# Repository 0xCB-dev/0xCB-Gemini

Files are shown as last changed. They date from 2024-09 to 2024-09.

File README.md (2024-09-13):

# 0xCB-Gemini

### 0xCB Helios little brother - waveshare zero compatible

| Licence | OSHWA |
| :---: | :---: |
|  | (https://certification.oshwa.org/de000147.html) |

### Official vendors

Purchasing Gemini from any vendors listed here directly supports our work. Gemini controllers sourced from vendors not listed here and not produced by us will not receive the same level of support and may have varying degrees of quality.

### EU:

Germany: [KeebSupply](https://keeb.supply/products/0xcb-gemini)

Germany: [Keycapsss](https://keycapsss.com/keyboard-parts/mcu-controller/277/0xcb-gemini-waveshare-rp2040-zero-compatible-microcontroller)

### North America:

America: Ringer Keys (Coming soon!)

#### Flashing

- `qmk clone`
- `cd qmk_firmware`
- To go to bootloader press the reset button longer than 500ms and release. Alternatively you can short the RST pin to GND, as it's wired to the reset button.
- `make 0xcb/gemini:default:flash`

### Assembly

The PCBs are assembled at the fab with the production files located in the /kikit/prod/ dir.

### Integration in your own design

- Waveshare zero footprint
- more to come

### PCB

KiCad 8 stable

[Schematic](https://github.com/0xCB-dev/0xcb-Gemini/blob/main/rev1.0/gemini.pdf)

### Pinout

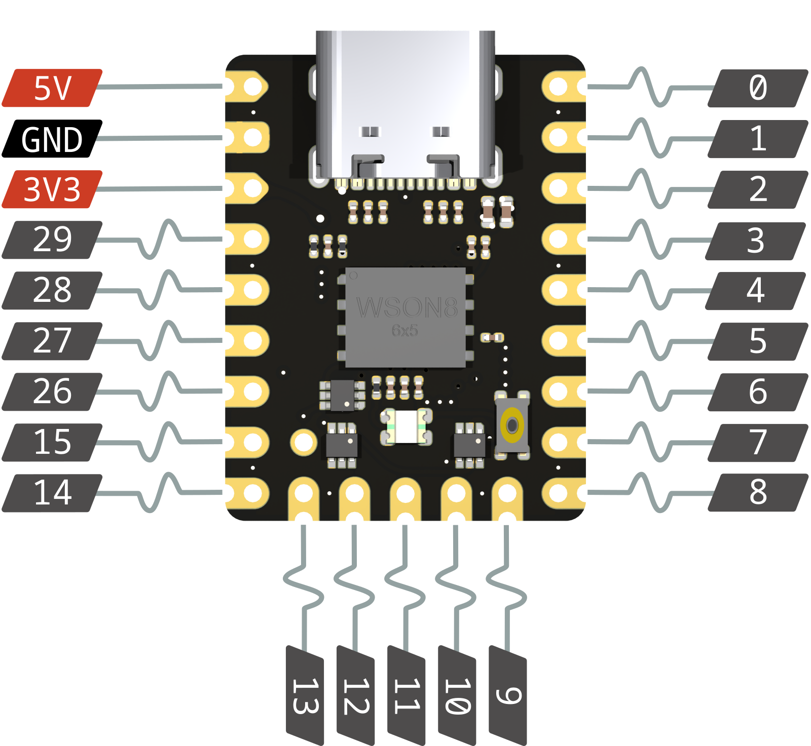
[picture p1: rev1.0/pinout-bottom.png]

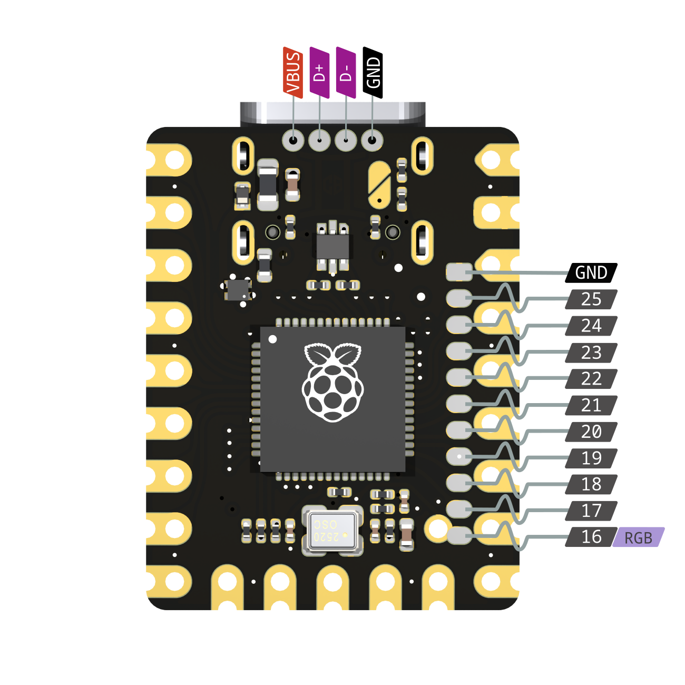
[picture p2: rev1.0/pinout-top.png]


| GPIO | F1 | F2 | F3 | F4 | F5  | F6 | F7 | F8 | F9 |
| ---- | --- | --- | --- | --- | --- | ---- | ---- | --- | --- |
| 0 | SPI0 RX  | UART0 TX  | I2C0 SDA | PWM0 A | SIO | PIO0 | PIO1 | | USB OVCUR DET |
| 1 | SPI0 CSn | UART0 RX  | I2C0 SCL | PWM0 B | SIO | PIO0 | PIO1 | | USB VBUS DET  |
| 2 | SPI0 SCK | UART0 CTS | I2C1 SDA | PWM1 A | SIO | PIO0 | PIO1 | | USB VBUS EN |
| 3 | SPI0 TX  | UART0 RTS | I2C1 SCL | PWM1 B | SIO | PIO0 | PIO1 | | USB OVCUR DET |
| 4 | SPI0 RX  | UART1 TX  | I2C0 SDA | PWM2 A | SIO | PIO0 | PIO1 | | USB VBUS DET  |
| 5 | SPI0 CSn | UART1 RX  | I2C0 SCL | PWM2 B | SIO | PIO0 | PIO1 | | USB VBUS EN |
| 6 | SPI0 SCK | UART1 CTS | I2C1 SDA | PWM3 A | SIO | PIO0 | PIO1 | | USB OVCUR DET |
| 7 | SPI0 TX  | UART1 RTS | I2C1 SCL | PWM3 B | SIO | PIO0 | PIO1 | | USB VBUS DET  |
| 8 | SPI1 RX  | UART1 TX  | I2C0 SDA | PWM4 A | SIO | PIO0 | PIO1 | | USB VBUS EN |
| 9 | SPI1 CSn | UART1 RX  | I2C0 SCL | PWM4 B | SIO | PIO0 | PIO1 | | USB OVCUR DET |
| 10 | SPI1 SCK | UART1 CTS | I2C1 SDA | PWM5 A | SIO | PIO0 | PIO1 | | USB VBUS DET  |
| 11 | SPI1 TX  | UART1 RTS | I2C1 SCL | PWM5 B | SIO | PIO0 | PIO1 | | USB VBUS EN |
| 12 | SPI1 RX  | UART0 TX  | I2C0 SDA | PWM6 A | SIO | PIO0 | PIO1 | | USB OVCUR DET |
| 13 | SPI1 CSn | UART0 RX  | I2C0 SCL | PWM6 B | SIO | PIO0 | PIO1 | | USB VBUS DET  |
| 14 | SPI1 SCK | UART0 CTS | I2C1 SDA | PWM7 A | SIO | PIO0 | PIO1 | | USB VBUS EN |
| 15 | SPI1 TX  | UART0 RTS | I2C1 SCL | PWM7 B | SIO | PIO0 | PIO1 | | USB OVCUR DET |
| 16 | SPI0 RX  | UART0 TX  | I2C0 SDA | PWM0 A | SIO | PIO0 | PIO1 | | USB VBUS DET  |
| 17 | SPI0 CSn | UART0 RX  | I2C0 SCL | PWM0 B | SIO | PIO0 | PIO1 | | USB VBUS EN |
| 18 | SPI0 SCK | UART0 CTS | I2C1 SDA | PWM1 A | SIO | PIO0 | PIO1 | | USB OVCUR DET |
| 19 | SPI0 TX  | UART0 RTS | I2C1 SCL | PWM1 B | SIO | PIO0 | PIO1 | | USB VBUS DET  |
| 20 | SPI0 RX  | UART1 TX  | I2C0 SDA | PWM2 A | SIO | PIO0 | PIO1 | CLOCK GPIN0  | USB VBUS EN |
| 21 | SPI0 CSn | UART1 RX  | I2C0 SCL | PWM2 B | SIO | PIO0 | PIO1 | CLOCK GPOUT0 | USB OVCUR DET |
| 22 | SPI0 SCK | UART1 CTS | I2C1 SDA | PWM3 A | SIO | PIO0 | PIO1 | CLOCK GPIN1  | USB VBUS DET  |
| 23 | SPI0 TX  | UART1 RTS | I2C1 SCL | PWM3 B | SIO | PIO0 | PIO1 | CLOCK GPOUT1 | USB VBUS EN |
| 24 | SPI1 RX  | UART1 TX  | I2C0 SDA | PWM4 A | SIO | PIO0 | PIO1 | CLOCK GPOUT2 | USB OVCUR DET |
| 25 | SPI1 CSn | UART1 RX  | I2C0 SCL | PWM4 B | SIO | PIO0 | PIO1 | CLOCK GPOUT3 | USB VBUS DET  |
| 26 | SPI1 SCK | UART1 CTS | I2C1 SDA | PWM5 A | SIO | PIO0 | PIO1 | | USB VBUS EN |
| 27 | SPI1 TX  | UART1 RTS | I2C1 SCL | PWM5 B | SIO | PIO0 | PIO1 | | USB OVCUR DET |
| 28 | SPI1 RX  | UART0 TX  | I2C0 SDA | PWM6 A | SIO | PIO0 | PIO1 | | USB VBUS DET  |
| 29 | SPI1 CSn | UART0 RX  | I2C0 SCL | PWM6 B | SIO | PIO0 | PIO1 | | USB VBUS EN |

### Credits

Uses the same reset circuit found on the [0xCB-Helios](https://github.com/0xCB-dev/0xcb-Helios) which in turn is based on the one used on the [Sea-picro](https://github.com/joshajohnson/sea-picro) by joshajohnson and this very well written [article](https://acheronproject.com/reset_article_1/reset_article_1/) by the Acheron Project.

Thank you! :heart:

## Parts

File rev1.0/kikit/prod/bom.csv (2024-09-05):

Comment | Designator | Footprint | LCSC
100n | C6,C11,C12,C13,C14,C15,C16,C17,C18,C19,C20 | gemini:C_0201_0603Metric | C576431
RP2040 | U4 | gemini:RP2040-QFN-56 | C2040
10k | R1,R2,R3,R10,R16 | gemini:R_0201_0603Metric | C138117
15p | C7,C8 | gemini:C_0201_0603Metric | C85891
10u | C1,C3,C4,C5 | gemini:C_0402_1005Metric | C15525
51k | R4,R5,R6 | gemini:R_0201_0603Metric | C295806
1u | C9,C10 | gemini:C_0201_0603Metric | C76935
4.7u | C2 | gemini:C_0201_0603Metric | C335103
2N7002VC- | Q1,Q2 | gemini:SOT-563 | C504145
27 | R11,R12 | gemini:R_0201_0603Metric | C273295
500mA | F1 | gemini:Fuse_0603_1608Metric | C210357
SWITCH | SW1 | gemini:1.9x2.8mm SW | C589221
USB_C_Receptacle_USB2.0 | J1 | gemini:USB_C_Receptacle_GCT_USB4105-xx-A_16P_TopMnt_Horizontal | C2858270
1k | R9,R13 | gemini:R_0201_0603Metric | C138297
PMEG2010BELD | D1 | gemini:SOD882D | C552820
W25Q128JVPIQ | U3 | gemini:W25Q128JVPIQ | C190862
5.1k | R7,R8,R15 | gemini:R_0201_0603Metric | C473460
27R | R14 | gemini:R_0201_0603Metric | C273295
600R | FB1 | gemini:R_0402_1005Metric | C160977
74LVC1T45 | U5 | gemini:SOT-563 | C352970
TLV75533PDQNR | U2 | gemini:X2SON-4 | C2861882
12MHz | Y1 | gemini:Crystal_SMD_2520-4Pin_2.5x2.0mm | C2149204
WS2812B | D2 | gemini:LED_WS2812B-2020_PLCC4_2.0x2.0mm | C2976072
USBLC6-2P6 | U1 | gemini:SOT-666 | C2827693

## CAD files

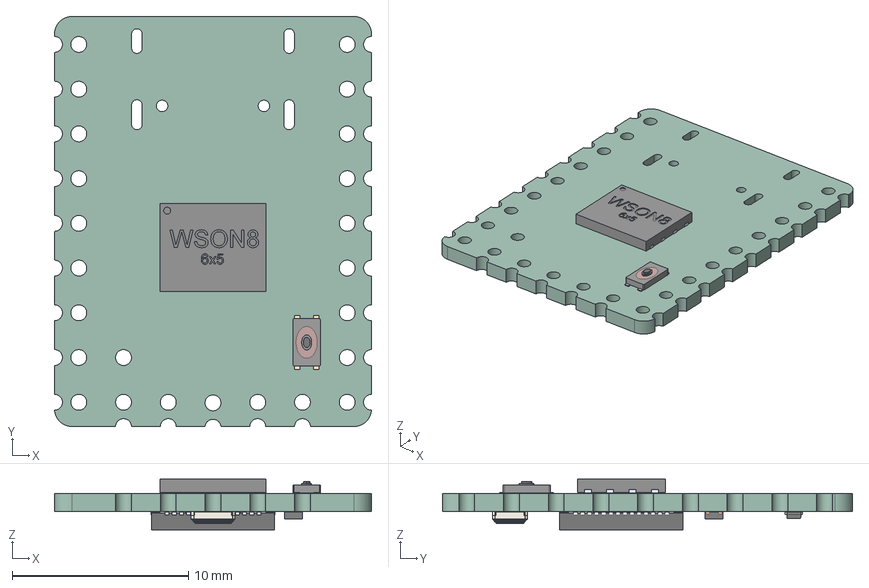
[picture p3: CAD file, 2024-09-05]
rev1.0/gemini.step
18.0 x 23.3 x 2.87 mm
PANASONIC_EVPAF7B70
WSON8-6x5
2520 SMD Crystal Oscillator
D_SOD_923
RP2040_QFN_PACKAGE
gemini_PCB

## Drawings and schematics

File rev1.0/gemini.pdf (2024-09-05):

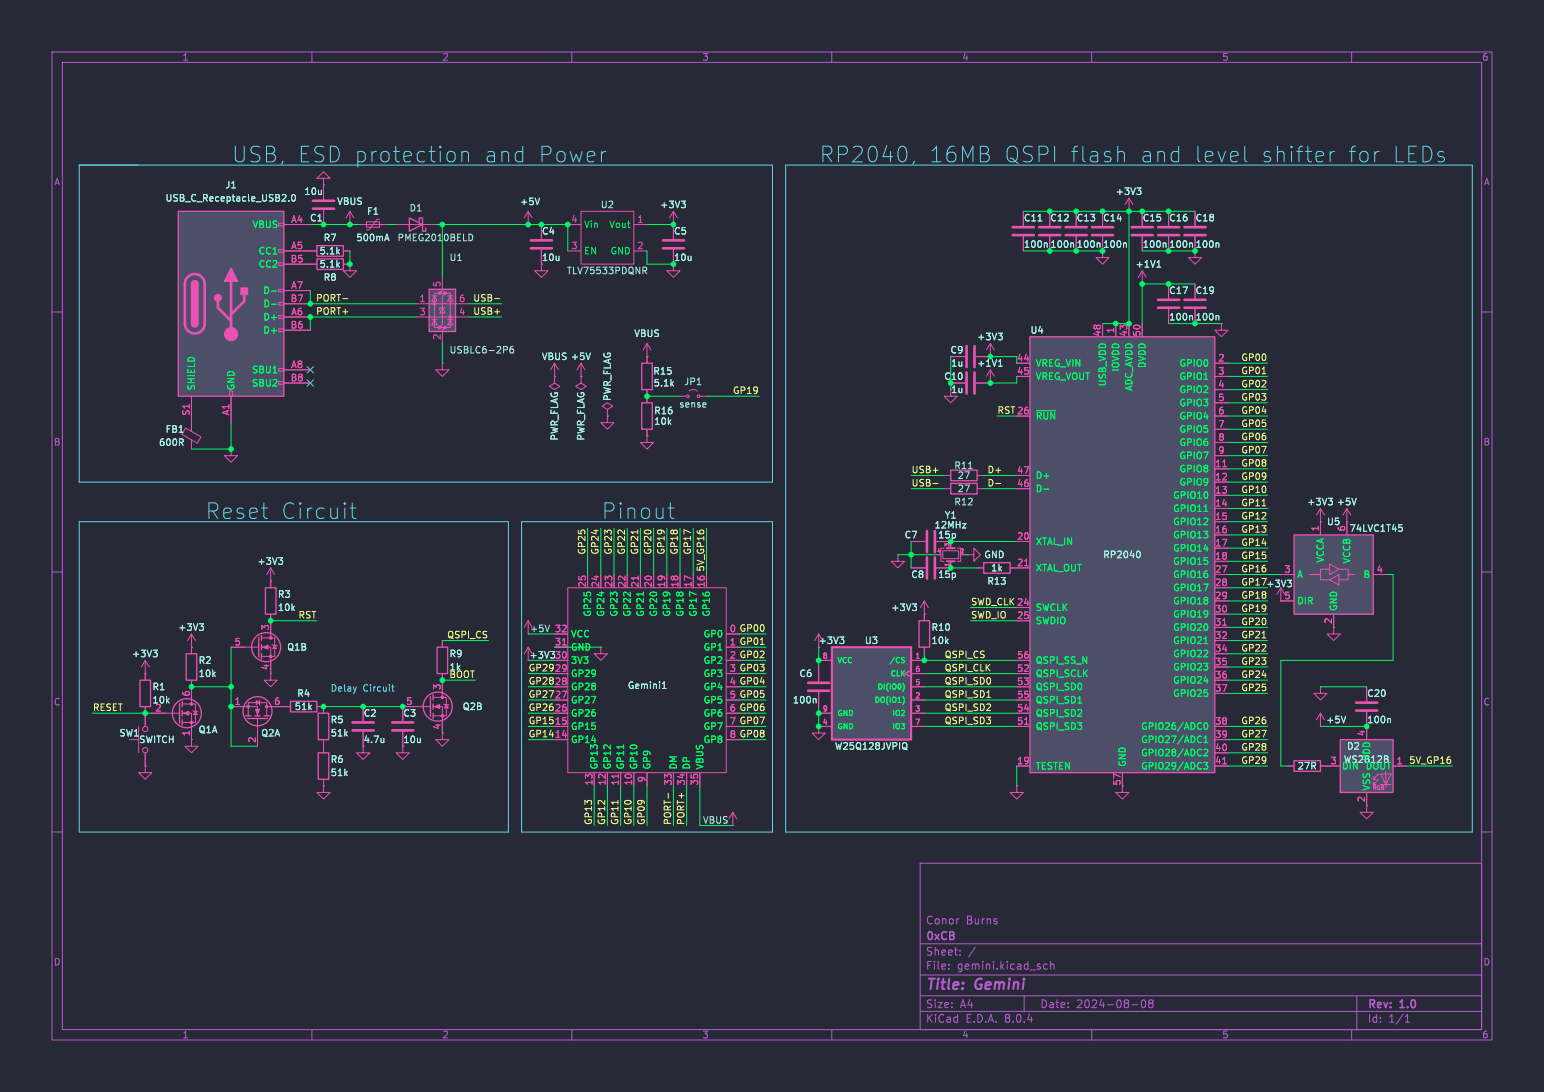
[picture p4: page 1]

RP2040, 16MB QSPI flash and level shifter for LEDs

1 GPIO8 11 GPIO9 12 GPIO10 13 GPIO11 14 GPIO12 15 GPIO13 16 GPIO14 17 GPIO15 18 TESTEN 19 GPIO0 2 XTAL_IN 20 XTAL_OUT 21 SWCLK 24 SWDIO 25 ~{RUN} 26 GPIO16 27 GPIO17 28 GPIO18 29 GPIO1 3 GPIO19 30 GPIO20 31 GPIO21 32 GPIO22 34 GPIO23 35 GPIO24 36 GPIO25 37 GPIO26/ADC0 38 GPIO27/ADC1 39 GPIO2 4 GPIO28/ADC2 40 GPIO29/ADC3 41 ADC_AVDD 43 VREG_VIN 44 VREG_VOUT 45 D- 46 D+ 47 USB_VDD 48 GPIO3 5 DVDD 50 QSPI_SD3 51 QSPI_SCLK 52 QSPI_SD0 53 QSPI_SD2 54 QSPI_SD1 55 QSPI_SS_N 56 GND 57 GPIO4 6 GPIO5 7 GPIO6 8 GPIO7 9 C7 15p FB1

1 GPIO8 11 GPIO9 12 GPIO10 13 GPIO11 14 GPIO12 15 GPIO13 16 GPIO14 17 GPIO15 18 TESTEN 19 GPIO0 2 XTAL_IN 20 XTAL_OUT 21 SWCLK 24 SWDIO 25 ~{RUN} 26 GPIO16 27 GPIO17 28 GPIO18 29 GPIO1 3 GPIO19 30 GPIO20 31 GPIO21 32 GPIO22 34 GPIO23 35 GPIO24 36 GPIO25 37 GPIO26/ADC0 38 GPIO27/ADC1 39 GPIO2 4 GPIO28/ADC2 40 GPIO29/ADC3 41 ADC_AVDD 43 VREG_VIN 44 VREG_VOUT 45 D- 46 D+ 47 USB_VDD 48 GPIO3 5 DVDD 50 QSPI_SD3 51 QSPI_SCLK 52 QSPI_SD0 53 QSPI_SD2 54 QSPI_SD1 55 QSPI_SS_N 56 GND 57 GPIO4 6 GPIO5 7 GPIO6 8 GPIO7 9 U4 RP2040 C7 15p R3

Conor Burns
Id: 1/1 Title: Gemini File: gemini.kicad_sch Sheet: / 0xCB

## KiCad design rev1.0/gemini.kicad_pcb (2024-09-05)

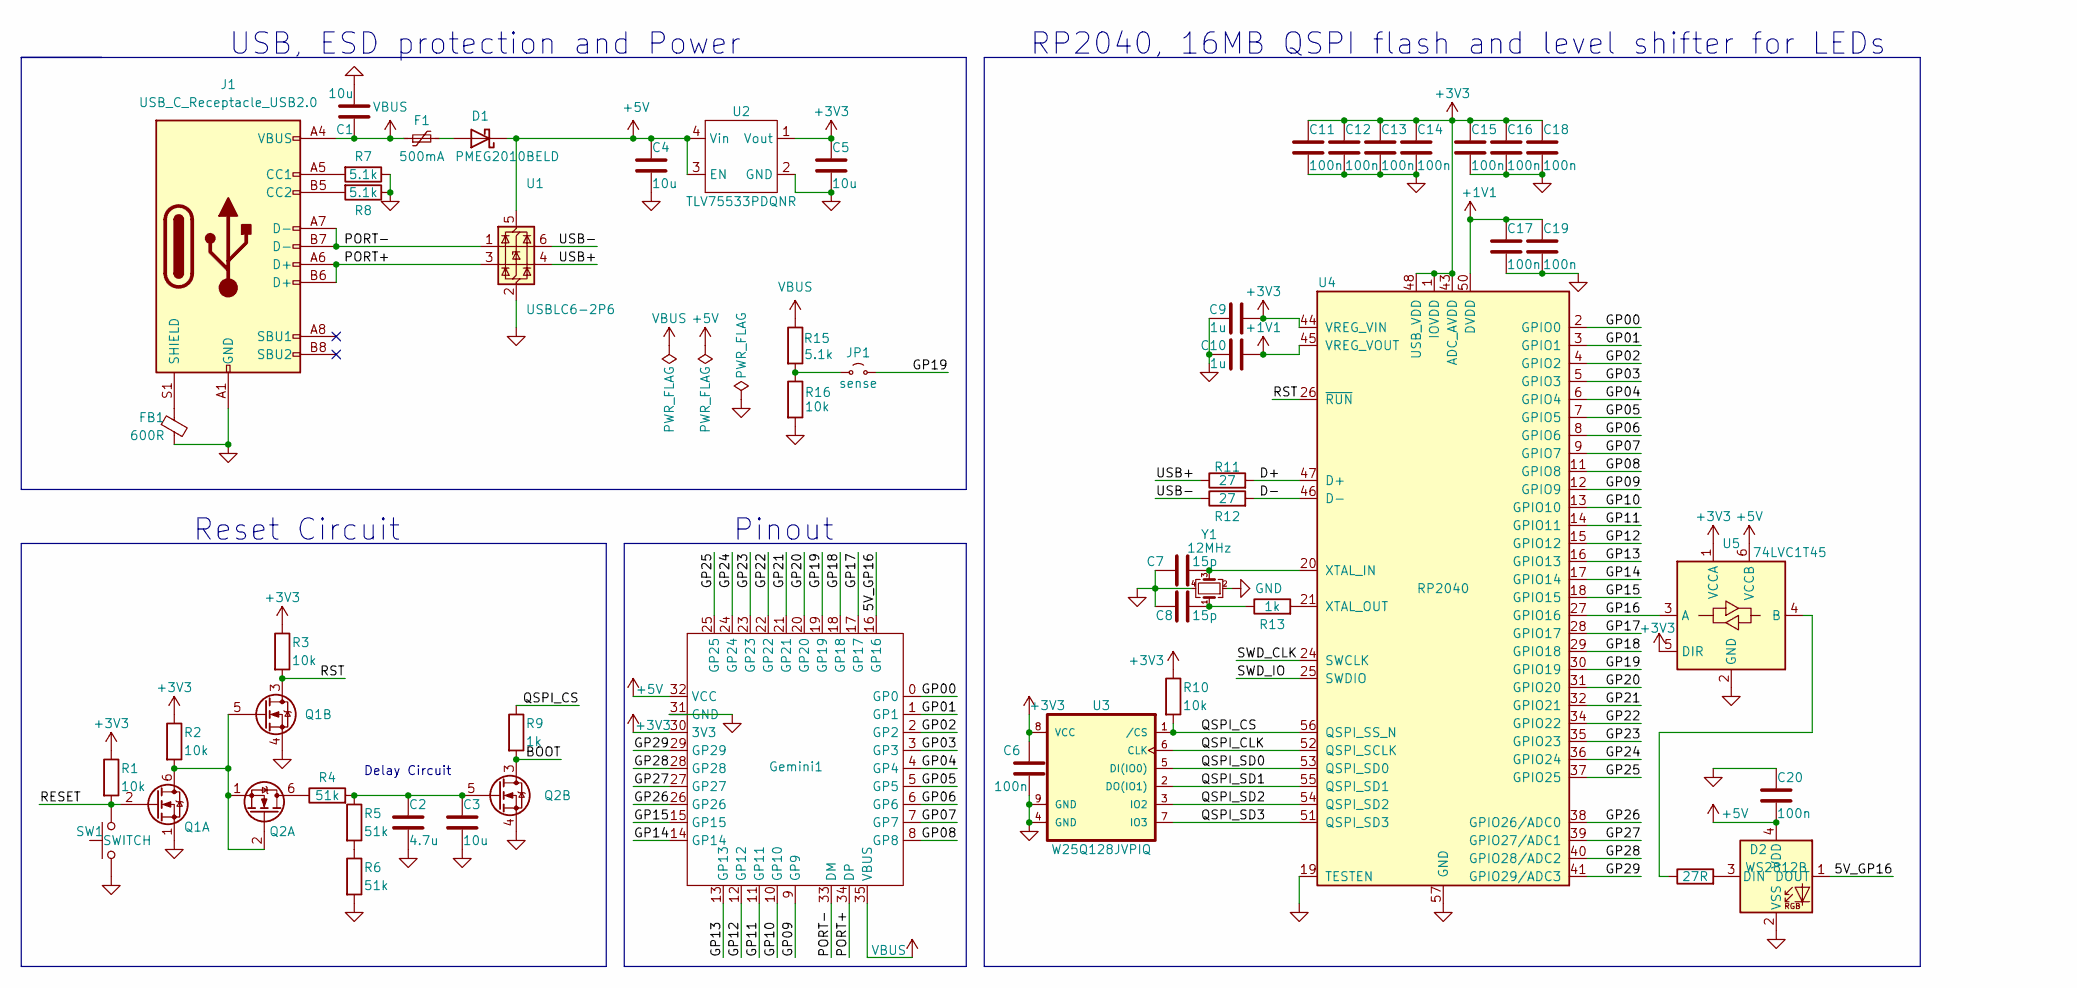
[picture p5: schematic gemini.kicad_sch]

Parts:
C1, C3, C4, C5: 10u; C_0402_1005Metric; MPN 10uF 20% 10V 0402; LCSC C15525
C2: 4.7u; C_0201_0603Metric; MPN 4.7uF 20% 10V 0402; LCSC C335103
C6, C11, C12, C13, C14, C15, C16, C17, C18, C19: 100n; C_0201_0603Metric; MPN 100nF 10% 10V 0402; LCSC C576431
C7, C8: 15p; C_0201_0603Metric; MPN 15pF 5% 10V; LCSC C85891
C9, C10: 1u; C_0201_0603Metric; MPN 1uF 20% 10V 0402; LCSC C76935
C20: 100n; C_0201_0603Metric; MPN CL05B104KO5NNNC; LCSC C576431
D1: PMEG2010BELD; SOD882D; MPN PMEG2010BELD,315; JLCPCB_CORRECTION 0; 0; 180
D2: WS2812B; LED_WS2812B-2020_PLCC4_2.0x2.0mm; MPN WS2812B-2020; LCSC C2976072
F1: 500mA; Fuse_0603_1608Metric; MPN MF-FSMF050X-2; LCSC C210357
FB1: 600R; R_0402_1005Metric; MPN BLM15PX601SN1D; LCSC C160977
Gemini1: gemini
J1: USB_C_Receptacle_USB2.0; USB_C_Receptacle_GCT_USB4105-xx-A_16P_TopMnt_Horizontal; MPN USB4510-03-1-A; JLCPCB_CORRECTION 0; -1; 0
JP1: sense; SolderJumper-Small
Q1, Q2: 2N7002VC-; SOT-563; MPN 2N7002VC; JLCPCB_CORRECTION 0; 0; 180
R1, R2, R3, R10, R16: 10k; R_0201_0603Metric; MPN 10k 1% 0402; LCSC C138117
R4, R5, R6: 51k; R_0201_0603Metric; MPN 51k 1% 0402; LCSC C295806
R7, R8, R15: 5.1k; R_0201_0603Metric; MPN 5.1k 1% 0402; LCSC C473460
R9, R13: 1k; R_0201_0603Metric; MPN 1k 1% 0402; LCSC C138297
R11, R12: 27; R_0201_0603Metric; MPN 27 1% 0402; LCSC C273295
R14: 27R; R_0201_0603Metric; MPN 0402WGF270JTCE; LCSC C273295
SW1: SWITCH; 1.9x2.8mm SW; MPN EVP-BL2A1B000; LCSC C589221
U1: USBLC6-2P6; SOT-666; MPN USBLC6-2P6; JLCPCB_CORRECTION 0; 0; 270
U2: TLV75533PDQNR; X2SON-4; MPN TLV75533PDQNR; JLCPCB_CORRECTION 0; 0; 180
U3: W25Q128JVPIQ; MPN W25Q128JVPIQ; JLCPCB_CORRECTION 0; 0; 270
U4: RP2040; RP2040-QFN-56; MPN SC0914(13); JLCPCB_CORRECTION 0; 0; 180
U5: 74LVC1T45; SOT-563; MPN SN74LVC1T45DRLR; JLCPCB_CORRECTION 0; 0; 270
Y1: 12MHz; Crystal_SMD_2520-4Pin_2.5x2.0mm; MPN ECS-120-10-36B-CWY-TR3; LCSC C2149204

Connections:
+1V1: C10.2, C17.1, C19.1, U4.23 (DVDD), U4.45 (VREG_VOUT), U4.50 (DVDD)
+3V3: C5.1, C6.1, C9.2, C11.1, C12.1, C13.1, C14.1, C15.1, C16.1, C18.1, Gemini1.30 (3V3), R1.1, R2.1, R3.1, R10.1, U2.1 (Vout), U3.8 (VCC), U4.1 (IOVDD), U4.10 (IOVDD), U4.22 (IOVDD), U4.33 (IOVDD), U4.42 (IOVDD), U4.43 (ADC_AVDD), U4.44 (VREG_VIN), U4.48 (USB_VDD), U4.49 (IOVDD), U5.1 (VCCA), U5.5 (DIR)
+5V: C4.1, C20.2, D1.1 (K), D2.4 (VDD), Gemini1.32 (VCC), U1.5 (VBUS), U2.3 (EN), U2.4 (Vin), U5.6 (VCCB)
/5V_GP16: D2.1 (DOUT), Gemini1.16 (GP16)
/BOOT: Q2.3 (D), R9.2
/D+: R11.2, U4.47 (D+)
/D-: R12.2, U4.46 (D-)
/GP00: Gemini1.0 (GP0), U4.2 (GPIO0)
/GP01: Gemini1.1 (GP1), U4.3 (GPIO1)
/GP02: Gemini1.2 (GP2), U4.4 (GPIO2)
/GP03: Gemini1.3 (GP3), U4.5 (GPIO3)
/GP04: Gemini1.4 (GP4), U4.6 (GPIO4)
/GP05: Gemini1.5 (GP5), U4.7 (GPIO5)
/GP06: Gemini1.6 (GP6), U4.8 (GPIO6)
/GP07: Gemini1.7 (GP7), U4.9 (GPIO7)
/GP08: Gemini1.8 (GP8), U4.11 (GPIO8)
/GP09: Gemini1.9 (GP9), U4.12 (GPIO9)
/GP10: Gemini1.10 (GP10), U4.13 (GPIO10)
/GP11: Gemini1.11 (GP11), U4.14 (GPIO11)
/GP12: Gemini1.12 (GP12), U4.15 (GPIO12)
/GP13: Gemini1.13 (GP13), U4.16 (GPIO13)
/GP14: Gemini1.14 (GP14), U4.17 (GPIO14)
/GP15: Gemini1.15 (GP15), U4.18 (GPIO15)
/GP16: U4.27 (GPIO16), U5.3 (A)
/GP17: Gemini1.17 (GP17), U4.28 (GPIO17)
/GP18: Gemini1.18 (GP18), U4.29 (GPIO18)
/GP19: Gemini1.19 (GP19), JP1.2 (B), U4.30 (GPIO19)
/GP20: Gemini1.20 (GP20), U4.31 (GPIO20)
/GP21: Gemini1.21 (GP21), U4.32 (GPIO21)
/GP22: Gemini1.22 (GP22), U4.34 (GPIO22)
/GP23: Gemini1.23 (GP23), U4.35 (GPIO23)
/GP24: Gemini1.24 (GP24), U4.36 (GPIO24)
/GP25: Gemini1.25 (GP25), U4.37 (GPIO25)
/GP26: Gemini1.26 (GP26), U4.38 (GPIO26/ADC0)
/GP27: Gemini1.27 (GP27), U4.39 (GPIO27/ADC1)
/GP28: Gemini1.28 (GP28), U4.40 (GPIO28/ADC2)
/GP29: Gemini1.29 (GP29), U4.41 (GPIO29/ADC3)
/PORT+: Gemini1.34 (DP), J1.A6 (D+), J1.B6 (D+), U1.3 (I/O2)
/PORT-: Gemini1.33 (DM), J1.A7 (D-), J1.B7 (D-), U1.1 (I/O1)
/QSPI_CLK: U3.6 (CLK), U4.52 (QSPI_SCLK)
/QSPI_CS: R9.1, R10.2, U3.1 (/CS), U4.56 (QSPI_SS_N)
/QSPI_SD0: U3.5 (DI(IO0)), U4.53 (QSPI_SD0)
/QSPI_SD1: U3.2 (DO(IO1)), U4.55 (QSPI_SD1)
/QSPI_SD2: U3.3 (IO2), U4.54 (QSPI_SD2)
/QSPI_SD3: U3.7 (IO3), U4.51 (QSPI_SD3)
/RESET: Q1.2 (G), R1.2, SW1.2
/RST: Q1.3 (D), R3.2, U4.26 (~RUN)
/SWD_CLK: U4.24 (SWCLK)
/SWD_IO: U4.25 (SWDIO)
/USB+: R11.1, U1.4 (I/O2)
/USB-: R12.1, U1.6 (I/O1)
GND: C1.2, C2.2, C3.2, C4.2, C5.2, C6.2, C7.1, C8.1, C9.1, C10.1, C11.2, C12.2, C13.2, C14.2, C15.2, C16.2, C17.2, C18.2, C19.2, C20.1, D2.2 (VSS), FB1.2, Gemini1.31 (GND), J1.A1 (GND), J1.A12 (GND), J1.B1 (GND), J1.B12 (GND), Q1.1 (S), Q1.4 (S), Q2.4 (S), R6.2, R7.1, R8.1, R16.2, SW1.1, U1.2 (GND), U2.2 (GND), U2.5 (TP), U3.4 (GND), U3.9 (GND), U4.19 (TESTEN), U4.57 (GND), U5.2 (GND), Y1.2, Y1.4
unnamed: C8.2, R13.1, Y1.1
unnamed: D1.2 (A), F1.2
unnamed: D2.3 (DIN), R14.2
unnamed: J1.A5 (CC1), R7.2
unnamed: J1.B5 (CC2), R8.2
unnamed: FB1.1, J1.S1 (SHIELD)
unnamed: JP1.1 (A), R15.2, R16.1
unnamed: Q1.5 (G), Q1.6 (D), Q2.1 (S), Q2.2 (G), R2.2
unnamed: Q2.6 (D), R4.1
unnamed: C2.1, C3.1, Q2.5 (G), R4.2, R5.1
unnamed: R5.2, R6.1
unnamed: C7.2, U4.20 (XTAL_IN), Y1.3
unnamed: R13.2, U4.21 (XTAL_OUT)
unnamed: R14.1, U5.4 (B)
VBUS: C1.1, F1.1, Gemini1.35 (VBUS), J1.A4 (VBUS), J1.A9 (VBUS), J1.B4 (VBUS), J1.B9 (VBUS), R15.1

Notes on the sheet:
RP2040, 16MB QSPI flash and level shifter for LEDs
USB, ESD protection and Power
Reset Circuit
Pinout
Delay Circuit

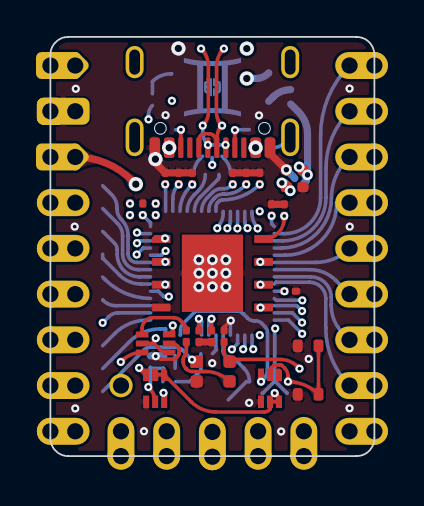
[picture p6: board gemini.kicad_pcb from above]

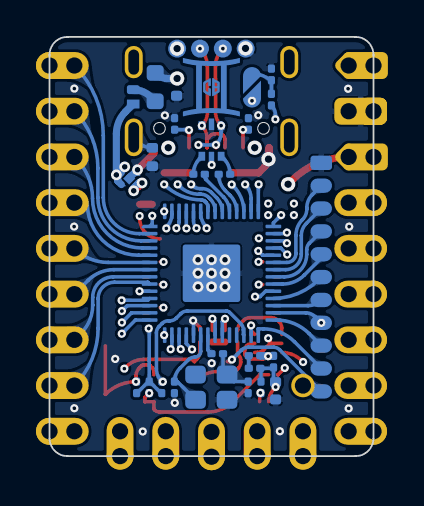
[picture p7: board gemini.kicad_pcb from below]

Board: 4 copper layers, 18.0 x 23.3 mm, 52 parts (26 on the bottom side), 65 nets.
